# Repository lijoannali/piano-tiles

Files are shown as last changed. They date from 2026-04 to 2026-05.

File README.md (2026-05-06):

# Piano Tiles 
A WS2812B LED array game written with "bare metal" C for the MSPM0G3507 for your simple entertainment needs...

## Demo Video
<a href="https://www.youtube.com/watch?v=3l9Rg3UBpZU">
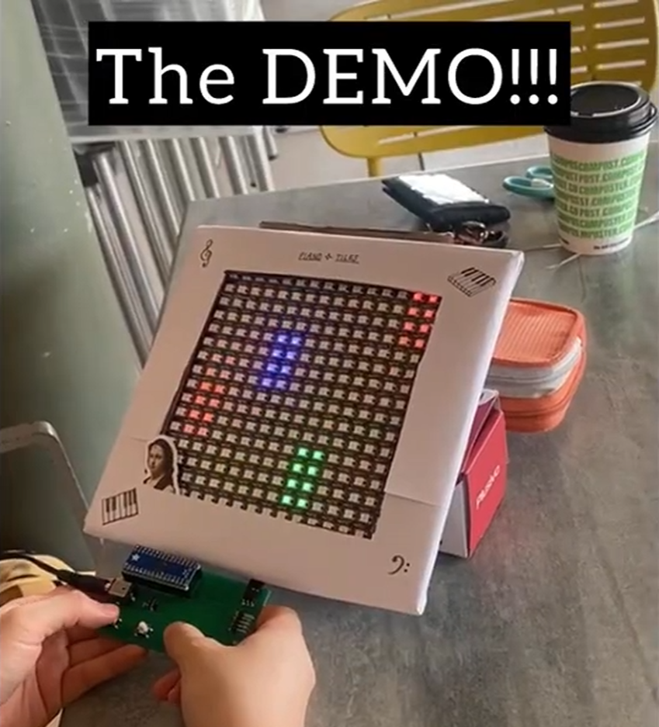
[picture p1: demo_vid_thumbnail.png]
  
</a>

# Full-Length Project Presentation
[Link to Video](https://www.youtube.com/watch?v=sYHI2Lu6KRk)

# Team Members
- Cindy Nguyen
- Maha Razzaq
- Joanna Li
- Ivana Zak
  
# Project Report
[Link to Report](/report.pdf)

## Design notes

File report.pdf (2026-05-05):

# Piano Tiles: A Real-Time Embedded Game on the MSPM0G3507

Maha Razzaq
Electrical and Computer Engineering Rice University
Houston, USA
mar30

Joanna Li
Electrical and Computer Engineering Rice University
Houston, USA
jl561

Cindy Nguyen
Electrical and Computer Engineering Rice University
Houston, USA
cn32

Ivana Zak
Electrical and Computer Engineering Rice University
Houston, USA
ivz1

Abstract—This paper describes the design and implementation of a real-time Piano Tiles game on the MSPM0G3507 microcontroller. The system uses a WS2812B 8x32 LED matrix as the display, driven over SPI from the MSPM0G3507, with four player buttons for input. Falling colored tile blocks scroll down two columns of the matrix, and the player scores by pressing the corresponding button as each tile enters the hit zone at the bottom of the screen. The firmware is organized around a tick-based state machine that handles tile movement, button debouncing, hit detection, scoring, and game-over conditions. The project demonstrates real-time processing, low-power sleep modes, hardware SPI communication with a custom WS2812B encoding scheme, and interrupt-driven timer operation.
Index Terms—real-time processing, low-power, hardware SPI communication, microcontroller
I. INTRODUCTION

Piano Tiles is a popular mobile game in which colored blocks fall down columns of a screen, and the player must tap the correct column at the right moment to score points. This project implements a physical version of this game using the Texas Instruments MSPM0G3507 microcontroller and a WS2812B 8x32 addressable LED matrix as the display. The motivation was to build an interactive, visually engaging embedded system that exercises the real-time processing and low-power capabilities of the MSPM0+ family.
The system is designed to run standalone without a laptop or launchpad, powered by a 5V supply. Push buttons serve as player input, one for each of the tile columns. The firmware manages all game logic, display rendering, and hardware communication in a bare-metal environment without operating system support, relying on a timer-interrupt-driven state machine running at approximately 1.6 ms per tick.

II. STATE MACHINE

The Piano Tiles game is organized around four top-level modes that form a simple loop. On power-on, the system starts in MODE_STARTUP_ANIM, which plays a scrolling blue row animation until any button is pressed. That press transitions the game into MODE_PLAYING, where tiles spawn and fall and the player’s button presses are evaluated. If the player accumulates too many misses (currently MISS_LIMIT = 1), the game transitions to MODE_LOSE_ANIM, which flashes the matrix red. If the player reaches the win score instead, it transitions to MODE_WIN_ANIM, which flashes green. Both end states loop their animations until any button is pressed, which calls InitGame() to reset all state and return to
MODE_STARTUP_ANIM.
The mode is stored as a game_mode_t enum field inside the game_state_t struct, which holds the entire game state — tiles, buttons, score, counters, and everything else. Rather than using global variables, the full state struct is passed by value into UpdateGame() each timer tick, and a new updated copy is returned. This design means the state machine is a pure function of its inputs: given the same state and the same GPIO reading, it always produces the same result. The only true globals in the system are the ISR flags timer_wakeup
and spi_transmission_in_progress, which are nec-
essary for communication between interrupt context and the main loop but are kept minimal and well-contained.
The MODE_PLAYING state governs tile spawning, the falling of each tile, registering and categorizing button presses, and game termination. First, a spawn counter periodically triggers the random creation of new tiles in one of several lanes. A tile spawns in a chosen random lane as long as there is no overlap with a previously spawned tile in that lane. Otherwise, a different random lane is chosen. Each active tile moves downward one row at a fixed rate of 240 ms after the end of a tile-falling counter is reached. The function also continually checks for button presses made by the player. If a player presses a button for a tile whose bottom row has not yet reached the bottom three rows of the LED array, the game transitions into the game loss animation. If the player fails to press the button in time, the game transitions into the game loss animation as well. If a player successfully presses the button for the tile at the correct time, the tile briefly turns green before being removed. The game only ends if the player loses.

The button state machine has three states: idle, debouncing, and held. The default state is idle. If a button press is detected (meaning a button pin reads 0), then the state becomes debouncing. If the button is continuously pressed for 30 ms or more, the state becomes held. Otherwise, it goes back to the idle state. While in the held state, if the button pin reads 1, then it goes back to the idle state.

III. FIRMWARE ARCHITECTURE

1) Graphics Function: To fit the MSPM0’s memory constraints, we could not store each frame of the LED animation as raw bytes. The microcontroller only has 32kb of RAM, and each one of the LED arrays in its full expanded form takes up 2kb of memory.
In our implementation on a 16 x 16 WS2812B array with 256 LEDs, we need 2*256 = 512 color bits. These are stored in the 64 byte (64*8 = 512 bits) framebuffer in which every 2 bits encodes the color of one LED. There are four defined constants of 0x00, 0x01, etc. which correspond to the LED being OFF, red, green, or blue.
Line segments are drawn to the array by using bit manipulation to locate the desired starting row, then writing only to the columns that span the length of the segment. Extending this, rectangles are drawn by iterating over multiple rows to span the width of a rectangle– before drawing a segment in each row that spans the height of the rectangle.
All of the graphics elements displayed at each state transition are accumulated into the frame buffer, and only expanded into the full WS2812B SPI message (written in a format where 3 SPI bits encode 1 bit of the color data) when the frame buffer is flushed at the end of each clock tick.
Besides the transmitted message, 0 bytes are written to signal a reset to the LED array at the end of drawing each frame so that a new frame can be taken in. Before drawing any rectangle at the start of each game frame, the frame buffer is cleared by setting all its values to 0 to turn off all the LEDs that were lit from the previous frame.

IV. HARDWARE ARCHITECTURE

The hardware architecture of our Piano Tiles-inspired game is centered around a custom-designed Printed Circuit Board (PCB). To simulate the classic feel of a handheld game console, we opted for a compact, wide rectangular shape measuring 8.5 x 5.5 cm. At the heart of this board is the 32-pin MSPM0 microcontroller, which controls the game logic, processes user inputs, and drives the visual output. The board integrates essential peripherals including a barrel power jack, four tactile push-buttons, and dedicated header pins for both system debugging and the external LED array.
Component placement was motivated by user experience and gameplay ergonomics. Power is supplied via a 3.3V barrel adapter, with the power jack and an accompanying On/Off switch strategically positioned on the left side of the board for easy access and connection. Because the external LED array acts as the primary screen and needs to sit directly in front of the player’s line of sight, its connection headers were routed to the top right of the PCB to keep cables out of the way. Meanwhile, the four tactile buttons, the primary interface for the game, are aligned in a horizontal row along the bottom edge. We carefully accounted for the spacing between these buttons to ensure a comfortable, responsive, and natural fingertapping experience during fast-paced gameplay.
Translating this layout into a functional PCB presented several routing and manufacturing challenges. We had to meticulously balance electrical constraints, making an effort to maximize trace widths for stable power delivery while maintaining reasonable clearance between traces, components, and board edges. Furthermore, we optimized our routing paths to minimize both overall trace lengths and the number of vias, ensuring better signal integrity and a cleaner board design. While the physical assembly, tiny component soldering, and hardware debugging proved to be quite a time-consuming process, it ultimately paid off when the board successfully powered up and seamlessly ran the game.

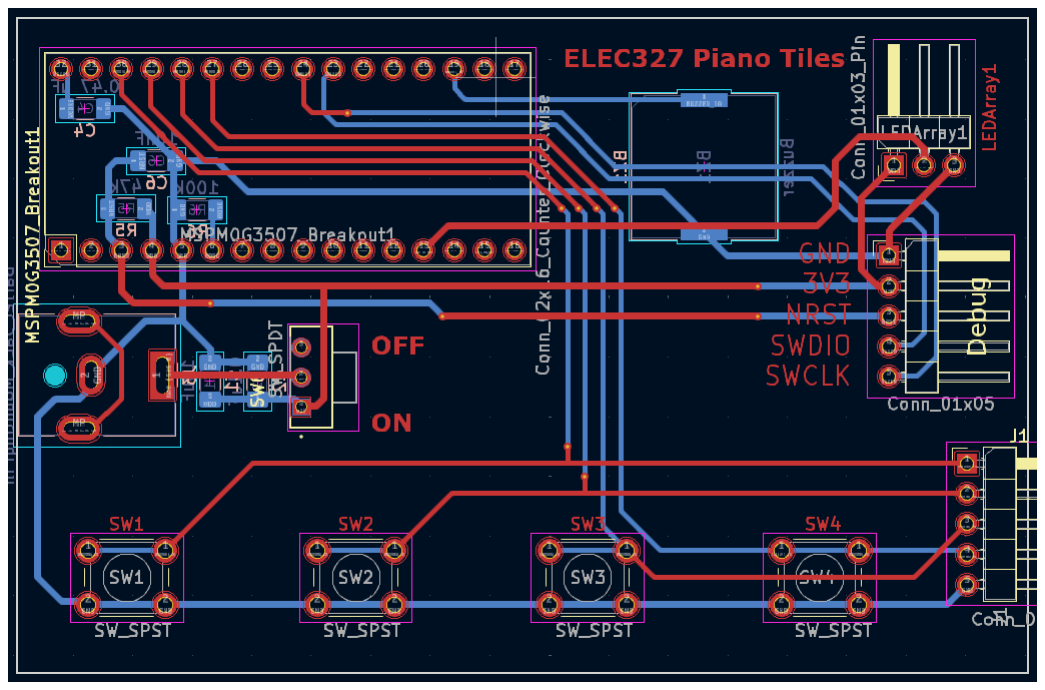
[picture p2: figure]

Fig. 1. Our PCB on a Screen

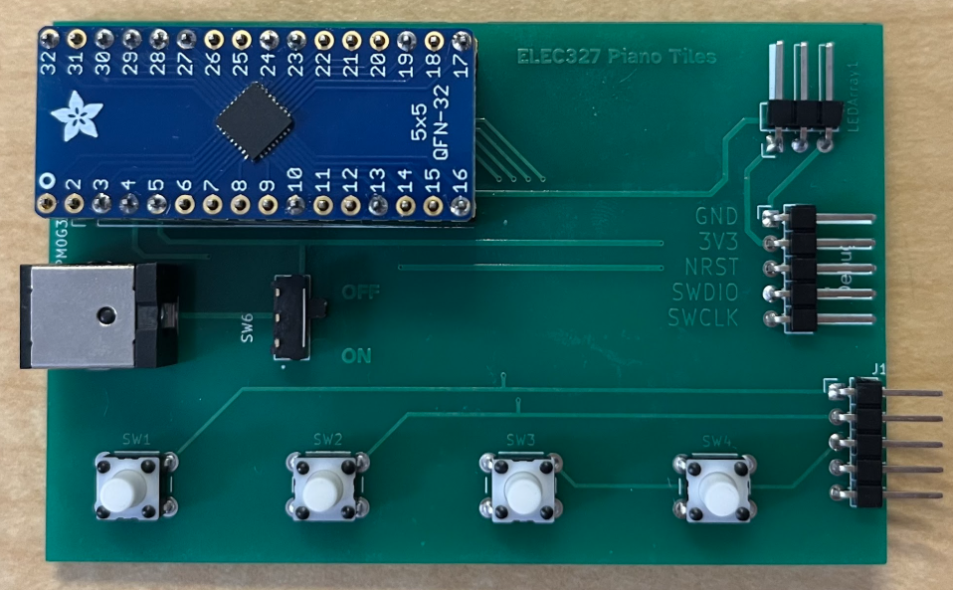
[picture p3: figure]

Fig. 2. Our PCB in Real Life

V. SLOC
We have also included our SLOC result below as a demonstration for the complexity of our code. 540 lines of code, excluding blanks and comments, making us fall in the range of 400-700 lines, with 8 extra credit points.

VI. CONCLUSION
We built a fully playable Piano Tiles game on the MSPM0G3507 using a 16×16 WS2812B LED matrix and 4

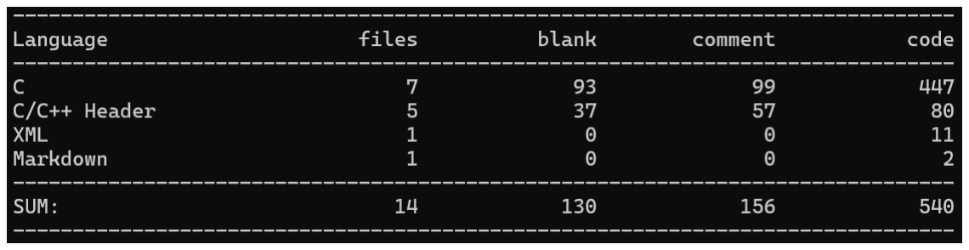
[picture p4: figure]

Fig. 3. SLOC Run Result

buttons in C. The project demonstrates core embedded systems concepts: real-time processing (state machine ticks every 30ms, buttons and tiles update deterministically), hardware SPI (WS2812B encoded as 3 SPI bits per LED bit at 2.67 MHz), and coding with C.

ACKNOWLEDGMENT
We would like to thank Dr. Kemere and class TAs for their continuous support throughout our final project.

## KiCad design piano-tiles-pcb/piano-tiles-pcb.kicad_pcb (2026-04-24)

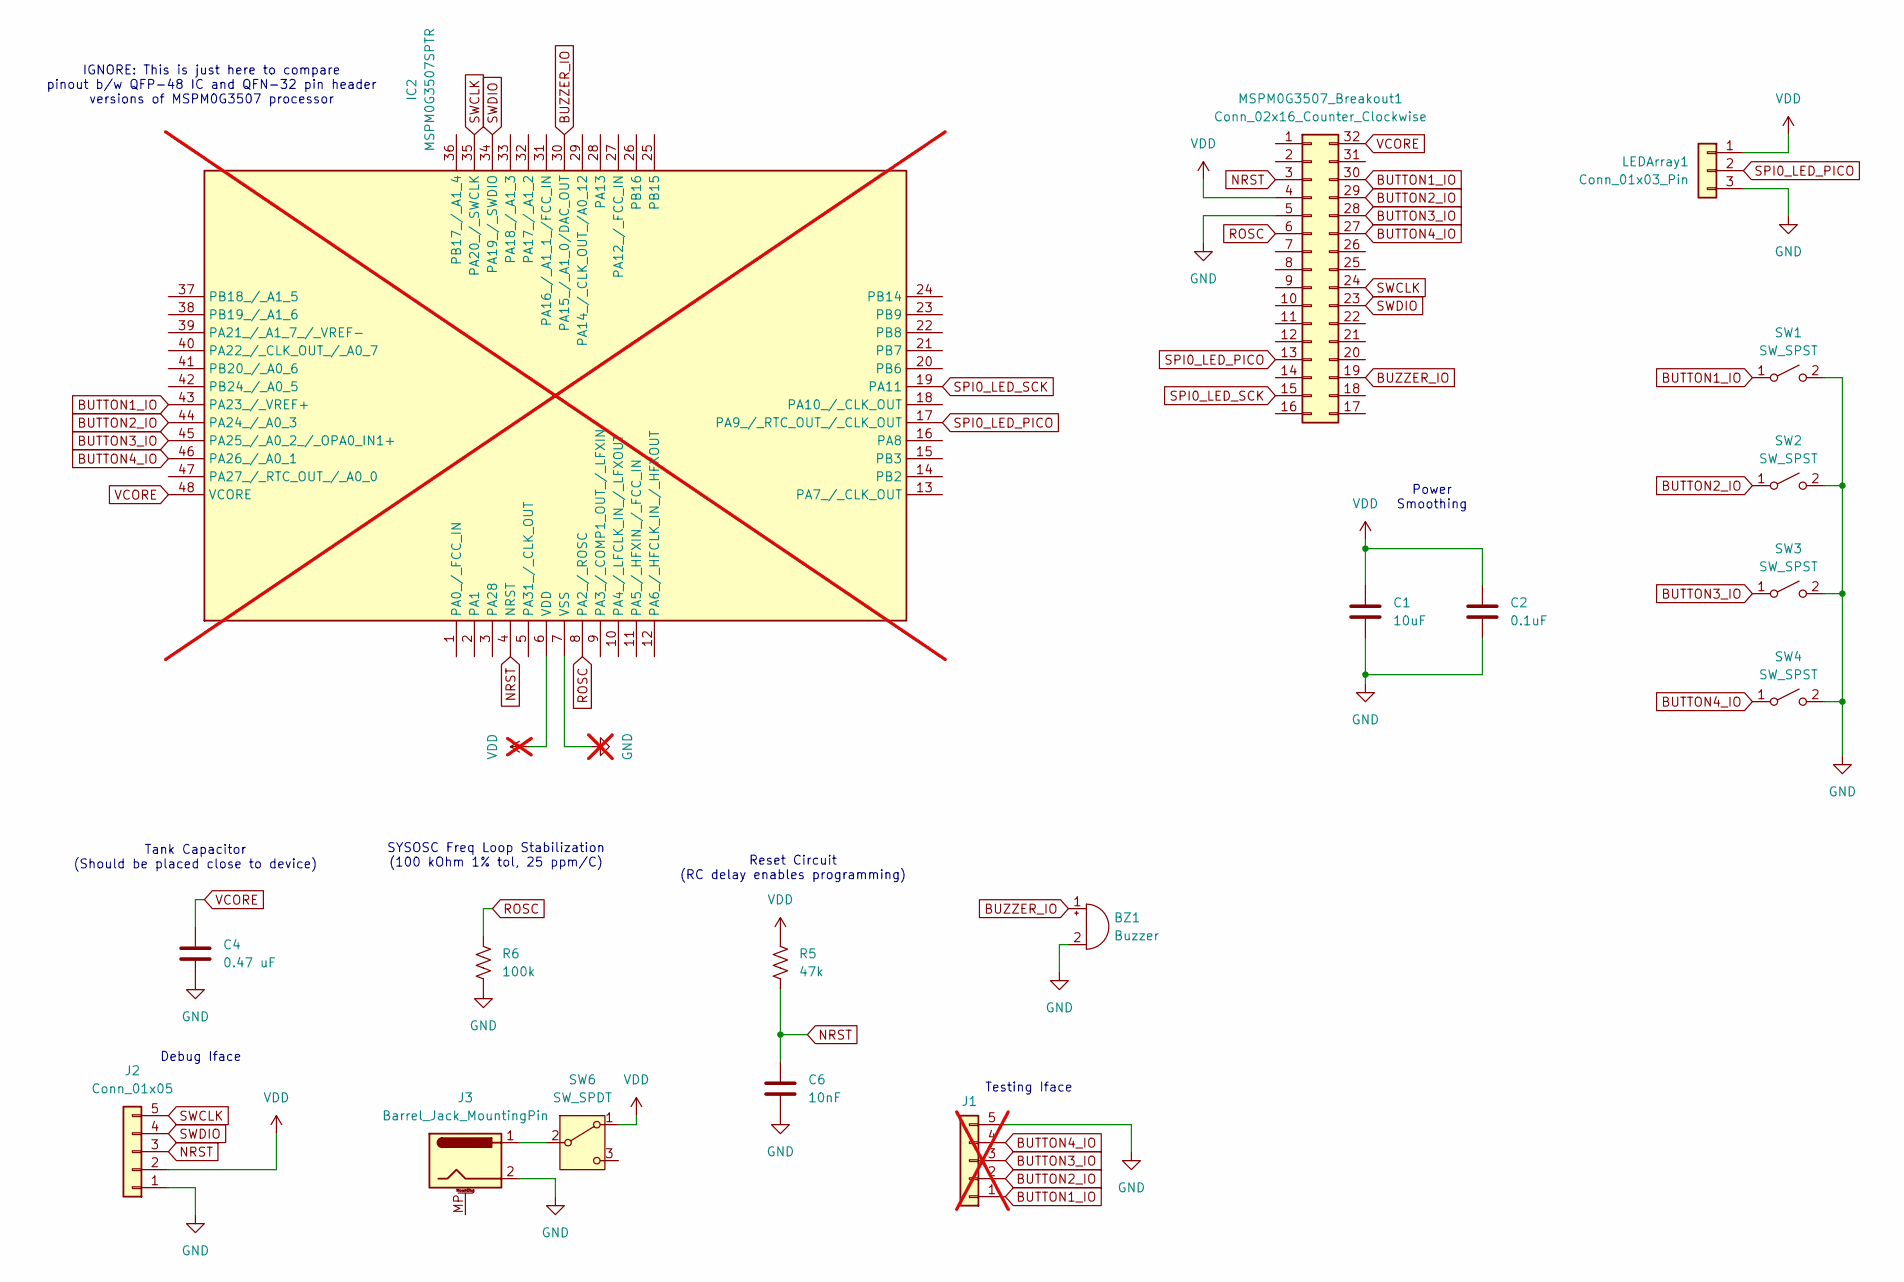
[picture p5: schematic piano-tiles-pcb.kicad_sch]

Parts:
BZ1: Buzzer; Buzzer_Murata_PKLCS1212E; LCSC Part # C113159
C1: 10uF; C_1206_3216Metric_Pad1.33x1.80mm_HandSolder
C2: 0.1uF; C_1206_3216Metric_Pad1.33x1.80mm_HandSolder
C4: 0.47 uF; C_1206_3216Metric_Pad1.33x1.80mm_HandSolder; LCSC Part # C13967
C6: 10nF; C_1206_3216Metric_Pad1.33x1.80mm_HandSolder; LCSC Part # C15195
IC2: MSPM0G3507SPTR; QFP50P900X900X160-48N; Mouser Part Number 595-MSPM0G3507SPTR; not fitted
J1: Conn_01x05; PinHeader_1x05_P2.54mm_Horizontal; not fitted
J2: Conn_01x05; PinHeader_1x05_P2.54mm_Horizontal; LCSC Part # C492413
J3: Barrel_Jack_MountingPin; BarrelJack_CUI_PJ-063AH_Horizontal
LEDArray1: Conn_01x03_Pin; PinHeader_1x03_P2.54mm_Horizontal
MSPM0G3507_Breakout1: Conn_02x16_Counter_Clockwise; QFN32Breakout-PinHeader_2x16_P2.54mm_Vertical
R5: 47k; R_1206_3216Metric_Pad1.30x1.75mm_HandSolder; LCSC Part # C105579
R6: 100k; R_1206_3216Metric_Pad1.30x1.75mm_HandSolder; LCSC Part # C60491
SW1, SW2, SW3, SW4: SW_SPST; SW_PUSH_6mm_H5mm
SW6: SW_SPDT; SW_EG1270; MPN C20611678; LCSC Part # C20611678

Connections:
BUTTON1_IO: IC2.43 (PA23_/_VREF+), J1.1, MSPM0G3507_Breakout1.30, SW1.1 (A)
BUTTON2_IO: IC2.44 (PA24_/_A0_3), J1.2, MSPM0G3507_Breakout1.29, SW2.1 (A)
BUTTON3_IO: IC2.45 (PA25_/_A0_2_/_OPA0_IN1+), J1.3, MSPM0G3507_Breakout1.28, SW3.1 (A)
BUTTON4_IO: IC2.46 (PA26_/_A0_1), J1.4, MSPM0G3507_Breakout1.27, SW4.1 (A)
BUZZER_IO: BZ1.1 (+), IC2.30 (PA15_/_A1_0/DAC_OUT), MSPM0G3507_Breakout1.19
GND: BZ1.2 (-), C1.2, C2.2, C4.2, C6.2, IC2.7 (VSS), J1.5, J2.1, J3.2, LEDArray1.3, MSPM0G3507_Breakout1.5, R6.1, SW1.2 (B), SW2.2 (B), SW3.2 (B), SW4.2 (B)
NRST: C6.1, IC2.4 (NRST), J2.3, MSPM0G3507_Breakout1.3, R5.1
unnamed: J3.1, SW6.2 (B)
ROSC: IC2.8 (PA2_/_ROSC), MSPM0G3507_Breakout1.6, R6.2
SPI0_LED_PICO: IC2.17 (PA9_/_RTC_OUT_/_CLK_OUT), LEDArray1.2, MSPM0G3507_Breakout1.13
SPI0_LED_SCK: IC2.19 (PA11), MSPM0G3507_Breakout1.15
SWCLK: IC2.35 (PA20_/_SWCLK), J2.5, MSPM0G3507_Breakout1.24
SWDIO: IC2.34 (PA19_/_SWDIO), J2.4, MSPM0G3507_Breakout1.23
VCORE: C4.1, IC2.48 (VCORE), MSPM0G3507_Breakout1.32
VDD: C1.1, C2.1, IC2.6 (VDD), J2.2, LEDArray1.1, MSPM0G3507_Breakout1.4, R5.2, SW6.1 (A)

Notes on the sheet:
Debug Iface
IGNORE: This is just here to compare pinout b/w QFP-48 IC and QFN-32 pin header versions of MSPM0G3507 processor
Reset Circuit (RC delay enables programming)
Power Smoothing
SYSOSC Freq Loop Stabilization (100 kOhm 1% tol, 25 ppm/C)
Testing Iface
Tank Capacitor (Should be placed close to device)

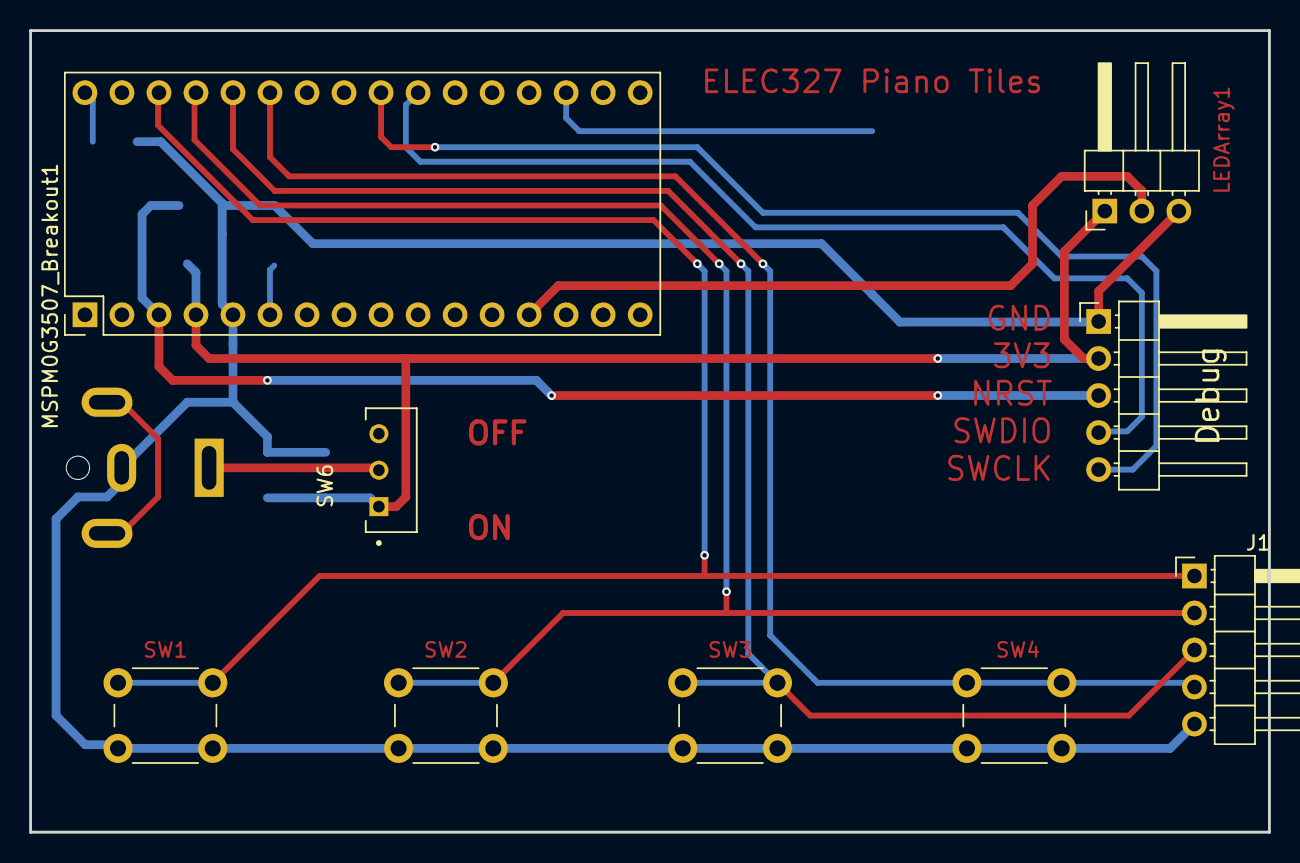
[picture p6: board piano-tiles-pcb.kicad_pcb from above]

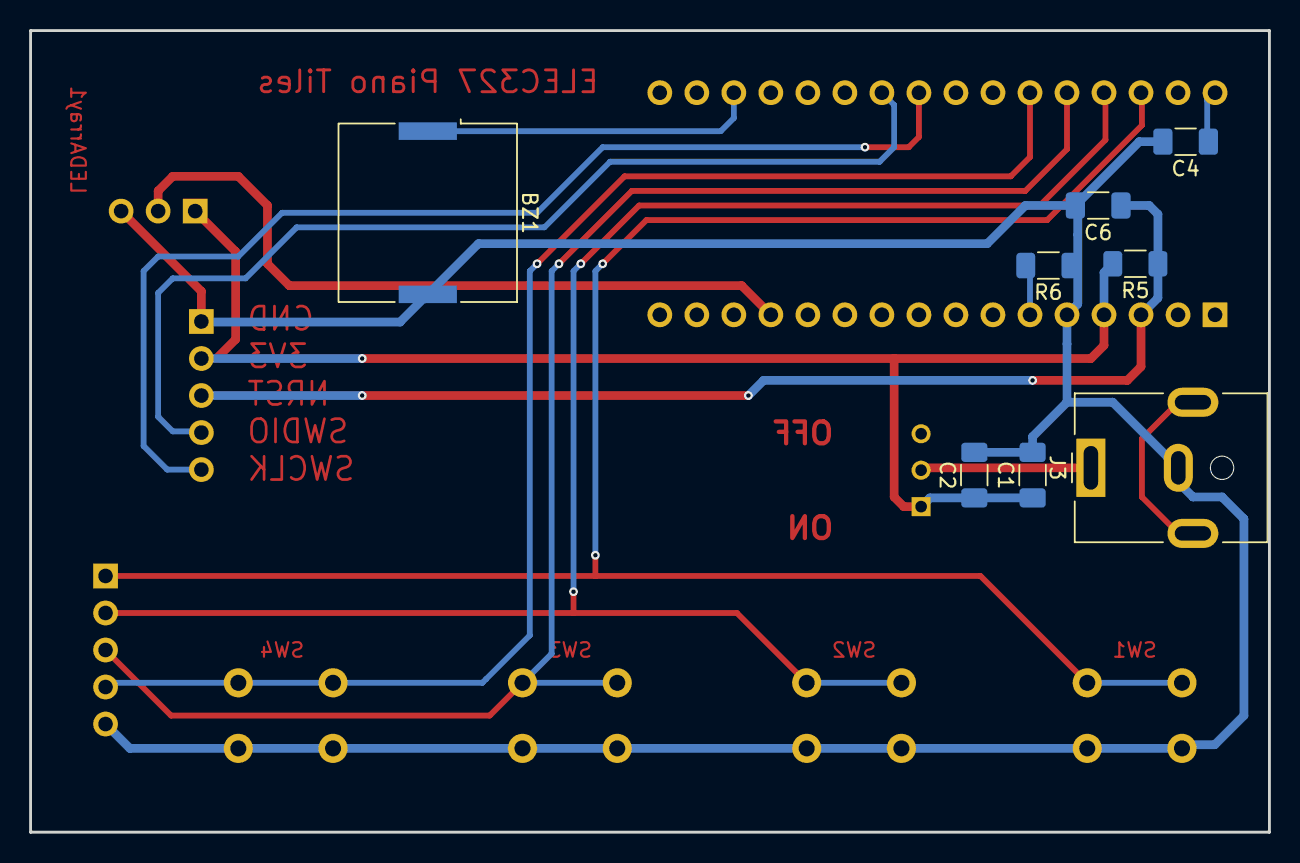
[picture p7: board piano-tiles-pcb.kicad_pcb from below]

Board: 2 copper layers, 85.0 x 55.0 mm, 17 parts (8 on the bottom side), 14 nets.

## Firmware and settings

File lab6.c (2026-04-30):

#include <ti/devices/msp/msp.h>
#include "delay.h"
#include "timing.h"
#include "leds.h"
#include "framebuffer.h"
#include "game.h"

#define SW1 ((uint32_t) 0x1 << 23)  // PA24
#define SW2 ((uint32_t) 0x1 << 24)  // PA25
#define SW3 ((uint32_t) 0x1 << 25)  // PA26
#define SW4 ((uint32_t) 0x1 << 26)  // PA27

void InitButtonGPIO(void) {
    if (GPIOA->GPRCM.STAT & GPIO_STAT_RESETSTKY_MASK) {
        GPIOA->GPRCM.RSTCTL = (GPIO_RSTCTL_KEY_UNLOCK_W |
                                GPIO_RSTCTL_RESETSTKYCLR_CLR |
                                GPIO_RSTCTL_RESETASSERT_ASSERT);
        GPIOA->GPRCM.PWREN  = (GPIO_PWREN_KEY_UNLOCK_W |
                                GPIO_PWREN_ENABLE_ENABLE);
        delay_cycles(POWER_STARTUP_DELAY);
    }
    const uint32_t cfg = IOMUX_PINCM_PC_CONNECTED |
                         IOMUX_PINCM_INENA_ENABLE  |
                         ((uint32_t) 0x00000001)   |
                         IOMUX_PINCM_PIPU_ENABLE   |
                         IOMUX_PINCM_PIPD_DISABLE;

    IOMUX->SECCFG.PINCM[IOMUX_PINCM53] = cfg;  // PA24
    IOMUX->SECCFG.PINCM[IOMUX_PINCM54] = cfg;  // PA25
    IOMUX->SECCFG.PINCM[IOMUX_PINCM55] = cfg;  // PA26
    IOMUX->SECCFG.PINCM[IOMUX_PINCM59] = cfg;  // PA27
    delay_cycles(POWER_STARTUP_DELAY);
}

int main(void) {
    InitializeLEDInterface();
    InitializeTimerG0();
    InitButtonGPIO();

    delay_cycles(1600000);

    SetTimerG0Delay(983);  // LFCLK=32768Hz → ~30ms per tick
    EnableTimerG0();

    game_state_t state = InitGame();

    while (1) {
        if (          timer_wakeup) {
            timer_wakeup = false;
            uint32_t input = GPIOA->DIN31_0 & (SW1 | SW2 | SW3 | SW4);
            state = UpdateGame(state, input);
            RenderGame(state);
        }
        __WFI();
    }
}

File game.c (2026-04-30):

#include "game.h"
#include "framebuffer.h"
#include "delay.h"
#include <ti/devices/msp/msp.h>

#define SW1 ((uint32_t) 0x1 << 23)  // PA24
#define SW2 ((uint32_t) 0x1 << 24)  // PA25
#define SW3 ((uint32_t) 0x1 << 25)  // PA26
#define SW4 ((uint32_t) 0x1 << 26)  // PA27
// 16 cols split into 4 lanes of 4 cols each.
// Tile is 2 cols wide, centered in its lane.
// Lane 0: cols 0-3,  tile at col 1
// Lane 1: cols 4-7,  tile at col 5
// Lane 2: cols 8-11, tile at col 9
// Lane 3: cols 12-15,tile at col 13
static const int TILE_COL_START[4] = {1, 5, 9, 13};
static const int TILE_COL_WIDTH    = 2;
static const int TILE_ROW_HEIGHT   = 4;


static const uint8_t TILE_COLOR[4] = {
    COLOR_DIM_RED,
    COLOR_DIM_GREEN,
    COLOR_DIM_BLUE,
    COLOR_DIM_RED
};

#define HIT_FLASH_TICKS  6

static uint32_t rng_state = 12345;
static uint32_t NextRand(void) {
    rng_state = rng_state * 1664525u + 1013904223u;
    return rng_state;
}

game_state_t InitGame(void) {
    game_state_t s;
    s.mode  = MODE_STARTUP_ANIM;
    s.score = 0;
    s.misses = 0;
    s.tick   = 0;
    s.anim_counter = 0;
    s.next_col = 0;
    s.spawn_counter = 0;
for (int i = 0; i < MAX_TILES; i++) {
    s.tiles[i].active = false;
    s.tiles[i].state  = TILE_GONE;
    s.tiles[i].row    = 0;
    s.tiles[i].lane   = 0;
    s.fall_counter[i] = 0;
}

for (int i = 0; i < NUM_LANES; i++) {
    s.buttons[i].state = BTN_IDLE;
    s.buttons[i].debounce_counter = 0;
    s.buttons[i].just_became_held = false;
    s.hit_flash[i] = 0;
}
    return s;
}

static btn_t UpdateButton(btn_t btn, bool raw_pressed) {
    btn_t b = btn;
    b.just_became_held = false;
    switch (btn.state) {
        case BTN_IDLE:
            if (raw_pressed) { b.state = BTN_DEBOUNCING; b.debounce_counter = 1; }
            break;
        case BTN_DEBOUNCING:
            if (raw_pressed) {
                b.debounce_counter++;
                if (b.debounce_counter >= DEBOUNCE_LIMIT) { b.state = BTN_HELD; b.just_became_held = true; }
            } else { b.state = BTN_IDLE; b.debounce_counter = 0; }
            break;
        case BTN_HELD:
            if (!raw_pressed) { b.state = BTN_IDLE; b.debounce_counter = 0; }
            break;
    }
    return b;
}

static tile_t SpawnTile(int lane) {
    tile_t t;
    t.active = true;
    t.row    = -TILE_ROW_HEIGHT;
    t.lane   = lane;
    t.state  = TILE_FALLING;
    return t;
}

game_state_t UpdateGame(game_state_t s, uint32_t gpio_input) {
    s.tick++;
    rng_state ^= s.tick;

    bool raw_btn[NUM_LANES];
    raw_btn[0] = ((gpio_input & SW1) == 0);
    raw_btn[1] = ((gpio_input & SW2) == 0);
    raw_btn[2] = ((gpio_input & SW3) == 0);
    raw_btn[3] = ((gpio_input & SW4) == 0);

    for (int i = 0; i < NUM_LANES; i++)
        s.buttons[i] = UpdateButton(s.buttons[i], raw_btn[i]);

    bool any_btn_just_held = false;
    for (int i = 0; i < NUM_LANES; i++)
        if (s.buttons[i].just_became_held) any_btn_just_held = true;

    for (int i = 0; i < NUM_LANES; i++)
        if (s.hit_flash[i] > 0) s.hit_flash[i]--;

    switch (s.mode) {

        case MODE_STARTUP_ANIM:
            s.anim_counter++;
            if (any_btn_just_held) {
                s.mode = MODE_PLAYING;
                s.score = 0; s.misses = 0; s.spawn_counter = 0;
for (int i = 0; i < MAX_TILES; i++) {
    s.tiles[i].active = false;
    s.tiles[i].state = TILE_GONE;
    s.tiles[i].row = 0;
    s.tiles[i].lane = 0;
    s.fall_counter[i] = 0;
}

for (int i = 0; i < NUM_LANES; i++) {
    s.buttons[i].state = BTN_IDLE;
    s.buttons[i].debounce_counter = 0;
    s.buttons[i].just_became_held = false;
    s.hit_flash[i] = 0;
}
               s.next_col = (NextRand() ^ s.tick) % NUM_LANES;
                s.tiles[0] = SpawnTile(s.next_col);
               s.fall_counter[0] = 0;
            }
            break;

case MODE_PLAYING: {
    s.spawn_counter++;
    
    
    if (s.spawn_counter >= SPAWN_GAP) {
        int start_lane = NextRand() % NUM_LANES;
        bool spawned = false;
        for (int attempt = 0; attempt < NUM_LANES && !spawned; attempt++) {
            int lane = (start_lane + attempt) % NUM_LANES;
            bool lane_clear = true;
            for (int j = 0; j < MAX_TILES; j++) {
                if (s.tiles[j].active && s.tiles[j].lane == lane) {
                    if (s.tiles[j].row < TILE_ROW_HEIGHT + 2) {
                        lane_clear = false;
                        break;
                    }
                }
            }
            if (!lane_clear) continue;
            for (int i = 0; i < MAX_TILES; i++) {
                if (!s.tiles[i].active) {
                    s.tiles[i] = SpawnTile(lane);
                    s.fall_counter[i] = 0;
                    spawned = true;
                    break;
                }
            }
        }
        s.spawn_counter = 0;
    }

    
    for (int i = 0; i < MAX_TILES; i++) {
        if (!s.tiles[i].active) continue;

        s.fall_counter[i]++;
        if (s.fall_counter[i] >= FALL_SPEED) {
            s.fall_counter[i] = 0;
            s.tiles[i].row++;
        }

        
        if (s.tiles[i].row >= MATRIX_ROWS) {
            s.misses++;
            s.tiles[i].active = false;
            s.tiles[i].state = TILE_GONE;
        }
    }

    
    for (int l = 0; l < NUM_LANES; l++) {
        
        if (s.buttons[l].just_became_held) {
            int target_idx = -1;
            int max_row = -100;

            
            for (int i = 0; i < MAX_TILES; i++) {
                if (s.tiles[i].active && s.tiles[i].lane == l) {
                    if (s.tiles[i].row > max_row) {
                        max_row = s.tiles[i].row;
                        target_idx = i;
                    }
                }
            }

            
if (target_idx != -1) {
    int bottom = s.tiles[target_idx].row + TILE_ROW_HEIGHT - 1;

    if (bottom >= MATRIX_ROWS - 3) {
      
        s.tiles[target_idx].active = false;
        s.tiles[target_idx].state = TILE_GONE;
        s.score++;
        s.hit_flash[l] = HIT_FLASH_TICKS;
    } else {
        
        s.misses++;
    }
}
        }
    }

    if (s.misses >= MISS_LIMIT) {
        s.mode = MODE_LOSE_ANIM;
        s.anim_counter = 0;
    }
    break;
}

        case MODE_WIN_ANIM:
        case MODE_LOSE_ANIM:
            s.anim_counter++;
            if (any_btn_just_held) { s = InitGame(); s.mode = MODE_STARTUP_ANIM; }
            break;
    }

    return s;
}
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

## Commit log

2026-04-04 Upload basic SPI setup to adapt to LED array
2026-04-08 Verify we can turn on GPIOB and PB8 for GPIO. Next step, turn on SPI on PB8
2026-04-08 We successfully sent SPI from PA9 PICO to the array. it did not light up red as intended, oops
2026-04-08 Fixed 0s from 000000 to the 100 zeros to match protocol of Ws2822b
    [lab6.c]
2026-04-12 PCB draft v1
    [piano-tiles-pcb.kicad_pcb, piano-tiles-pcb.kicad_sch]
2026-04-13 Adding buttons code
2026-04-15 Implement frame buffer for writing a row to LED array
2026-04-16 Add macros for led dimensions and bit packing
2026-04-16 Add blue and green as LED color options
2026-04-16 Fix SPI clock and setup
    [leds.c]
2026-04-16 Fix led header, remove unused functions
2026-04-17 Add initial selection of 4 GPIO pins for button input
2026-04-24 first order
    [piano-tiles-pcb.kicad_pcb, piano-tiles-pcb.kicad_sch]
